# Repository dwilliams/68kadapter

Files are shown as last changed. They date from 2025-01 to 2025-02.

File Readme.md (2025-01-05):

# 68030 to 68020 adapter

Barebones adapter for Motorola processors, converting 68030 to 68020. There is no logic in this, and all the extra features of the 68030 are disabled.

# Why was this made?

To be used with [https://rosco-m68k.com/](https://rosco-m68k.com/) 68020 SBC to test CPUs bought off eBay. Didn't want to buy both the '20 and the '30 version, and now I can test (to a large degree) both versions. The MMU isn't getting tested, but in practice the chips either all work or fail completely to even come up, so it met it's goal.

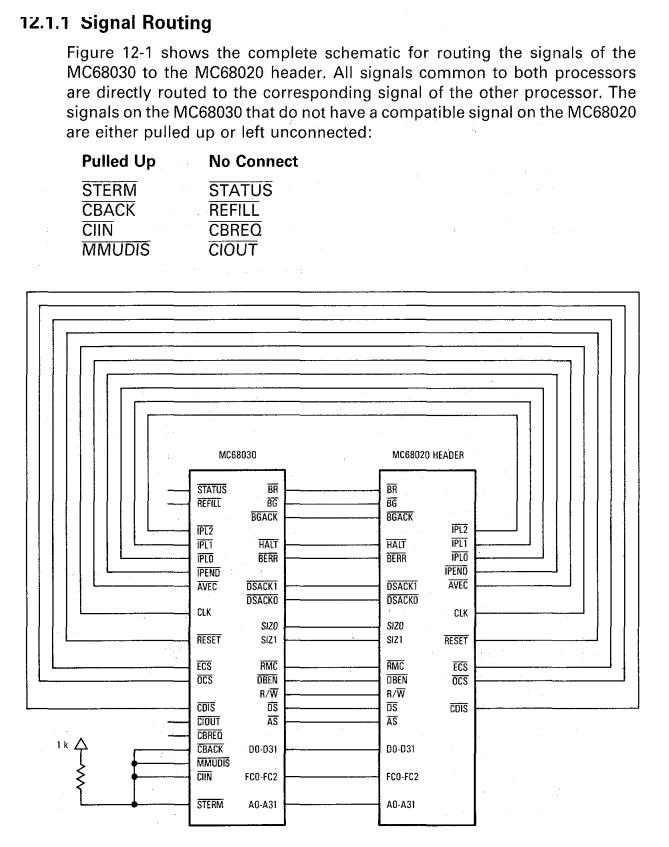
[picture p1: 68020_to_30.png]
Diagram


# Headers and socket

You can buy those off sites like DigiKey or eBay.

For the plug-in 68020 side I used 2.54 mm Single Row Male Pin Headers that I cut up to fill in the rows/columns as needed. They need to be aligned really well otherwise it's close to impossible to plug them into a socket. I used one of the non-populated boards (got 3 made for corrections, test, etc) to hold the pins in place in the right way, but you can also use a 68020 socket and get the same effect. The latter might be too much of a heat sink though, making soldering hard.

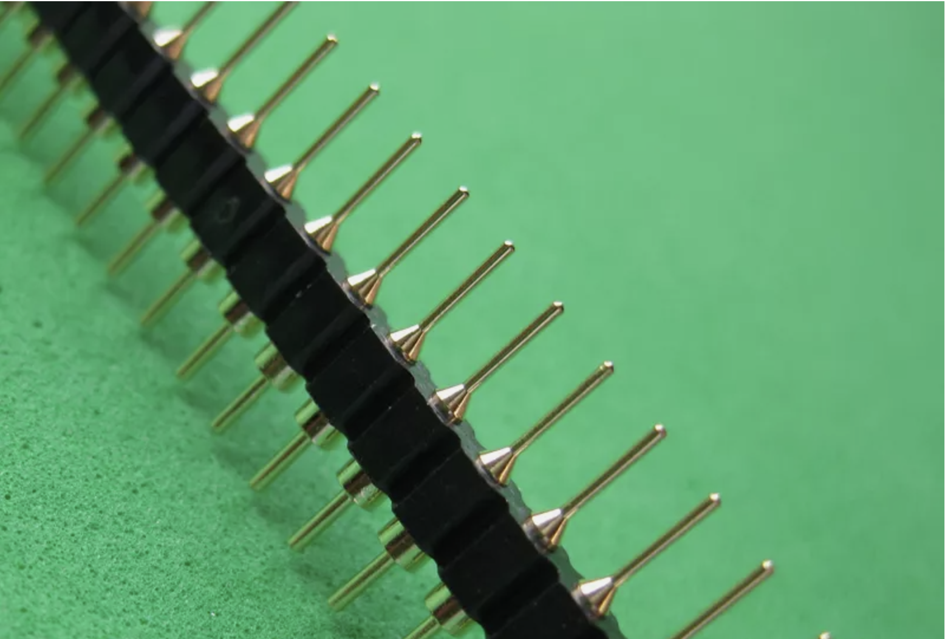
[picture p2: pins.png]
Pin Headers


The 68030 side is just a regular 128 Pin Machine Pin Grid Array PGA IC Socket.

PGA Socket

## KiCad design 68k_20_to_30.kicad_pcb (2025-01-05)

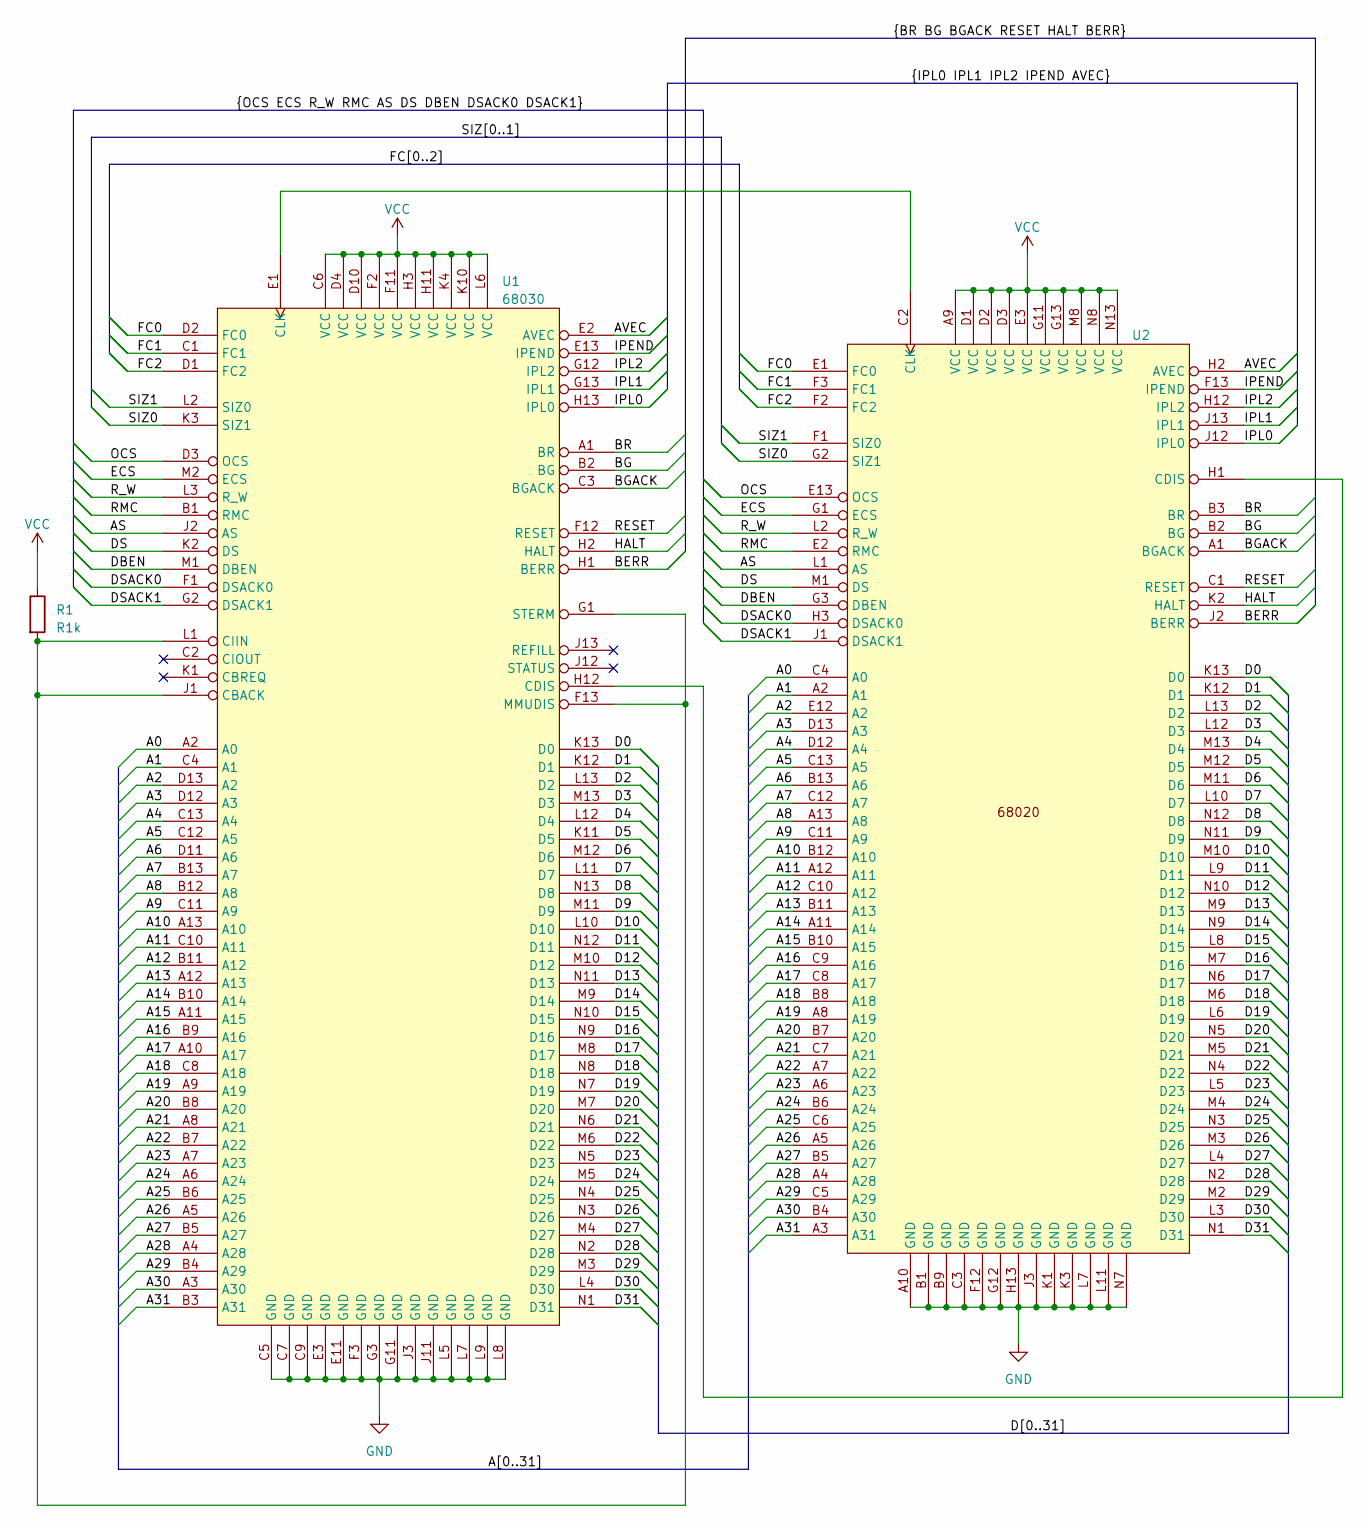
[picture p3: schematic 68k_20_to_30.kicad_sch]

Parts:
R1: R1k; R_Axial_DIN0204_L3.6mm_D1.6mm_P5.08mm_Horizontal
U1: 68030; PGA114_68030
U2: PGA114_68020

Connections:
/A0: U1.A2 (A0), U2.C4 (A0)
/A1: U1.C4 (A1), U2.A2 (A1)
/A2: U1.D13 (A2), U2.E12 (A2)
/A3: U1.D12 (A3), U2.D13 (A3)
/A4: U1.C13 (A4), U2.D12 (A4)
/A5: U1.C12 (A5), U2.C13 (A5)
/A6: U1.D11 (A6), U2.B13 (A6)
/A7: U1.B13 (A7), U2.C12 (A7)
/A8: U1.B12 (A8), U2.A13 (A8)
/A9: U1.C11 (A9), U2.C11 (A9)
/A10: U1.A13 (A10), U2.B12 (A10)
/A11: U1.C10 (A11), U2.A12 (A11)
/A12: U1.B11 (A12), U2.C10 (A12)
/A13: U1.A12 (A13), U2.B11 (A13)
/A14: U1.B10 (A14), U2.A11 (A14)
/A15: U1.A11 (A15), U2.B10 (A15)
/A16: U1.B9 (A16), U2.C9 (A16)
/A17: U1.A10 (A17), U2.C8 (A17)
/A18: U1.C8 (A18), U2.B8 (A18)
/A19: U1.A9 (A19), U2.A8 (A19)
/A20: U1.B8 (A20), U2.B7 (A20)
/A21: U1.A8 (A21), U2.C7 (A21)
/A22: U1.B7 (A22), U2.A7 (A22)
/A23: U1.A7 (A23), U2.A6 (A23)
/A24: U1.A6 (A24), U2.B6 (A24)
/A25: U1.B6 (A25), U2.C6 (A25)
/A26: U1.A5 (A26), U2.A5 (A26)
/A27: U1.B5 (A27), U2.B5 (A27)
/A28: U1.A4 (A28), U2.A4 (A28)
/A29: U1.B4 (A29), U2.C5 (A29)
/A30: U1.A3 (A30), U2.B4 (A30)
/A31: U1.B3 (A31), U2.A3 (A31)
/AS: U1.J2 (AS), U2.L1 (AS)
/AVEC: U1.E2 (AVEC), U2.H2 (AVEC)
/BERR: U1.H1 (BERR), U2.J2 (BERR)
/BG: U1.B2 (BG), U2.B2 (BG)
/BGACK: U1.C3 (BGACK), U2.A1 (BGACK)
/BR: U1.A1 (BR), U2.B3 (BR)
/D0: U1.K13 (D0), U2.K13 (D0)
/D1: U1.K12 (D1), U2.K12 (D1)
/D2: U1.L13 (D2), U2.L13 (D2)
/D3: U1.M13 (D3), U2.L12 (D3)
/D4: U1.L12 (D4), U2.M13 (D4)
/D5: U1.K11 (D5), U2.M12 (D5)
/D6: U1.M12 (D6), U2.M11 (D6)
/D7: U1.L11 (D7), U2.L10 (D7)
/D8: U1.N13 (D8), U2.N12 (D8)
/D9: U1.M11 (D9), U2.N11 (D9)
/D10: U1.L10 (D10), U2.M10 (D10)
/D11: U1.N12 (D11), U2.L9 (D11)
/D12: U1.M10 (D12), U2.N10 (D12)
/D13: U1.N11 (D13), U2.M9 (D13)
/D14: U1.M9 (D14), U2.N9 (D14)
/D15: U1.N10 (D15), U2.L8 (D15)
/D16: U1.N9 (D16), U2.M7 (D16)
/D17: U1.M8 (D17), U2.N6 (D17)
/D18: U1.N8 (D18), U2.M6 (D18)
/D19: U1.N7 (D19), U2.L6 (D19)
/D20: U1.M7 (D20), U2.N5 (D20)
/D21: U1.N6 (D21), U2.M5 (D21)
/D22: U1.M6 (D22), U2.N4 (D22)
/D23: U1.N5 (D23), U2.L5 (D23)
/D24: U1.M5 (D24), U2.M4 (D24)
/D25: U1.N4 (D25), U2.N3 (D25)
/D26: U1.N3 (D26), U2.M3 (D26)
/D27: U1.M4 (D27), U2.L4 (D27)
/D28: U1.N2 (D28), U2.N2 (D28)
/D29: U1.M3 (D29), U2.M2 (D29)
/D30: U1.L4 (D30), U2.L3 (D30)
/D31: U1.N1 (D31), U2.N1 (D31)
/DBEN: U1.M1 (DBEN), U2.G3 (DBEN)
/DS: U1.K2 (DS), U2.M1 (DS)
/DSACK0: U1.F1 (DSACK0), U2.H3 (DSACK0)
/DSACK1: U1.G2 (DSACK1), U2.J1 (DSACK1)
/ECS: U1.M2 (ECS), U2.G1 (ECS)
/FC0: U1.D2 (FC0), U2.E1 (FC0)
/FC1: U1.C1 (FC1), U2.F3 (FC1)
/FC2: U1.D1 (FC2), U2.F2 (FC2)
/HALT: U1.H2 (HALT), U2.K2 (HALT)
/IPEND: U1.E13 (IPEND), U2.F13 (IPEND)
/IPL0: U1.H13 (IPL0), U2.J12 (IPL0)
/IPL1: U1.G13 (IPL1), U2.J13 (IPL1)
/IPL2: U1.G12 (IPL2), U2.H12 (IPL2)
/OCS: U1.D3 (OCS), U2.E13 (OCS)
/RESET: U1.F12 (RESET), U2.C1 (RESET)
/RMC: U1.B1 (RMC), U2.E2 (RMC)
/R_W: U1.L3 (R_W), U2.L2 (R_W)
/SIZ0: U1.K3 (SIZ1), U2.G2 (SIZ1)
/SIZ1: U1.L2 (SIZ0), U2.F1 (SIZ0)
GND: U1.C5 (GND), U1.C7 (GND), U1.C9 (GND), U1.E3 (GND), U1.E11 (GND), U1.F3 (GND), U1.G3 (GND), U1.G11 (GND), U1.J3 (GND), U1.J11 (GND), U1.L5 (GND), U1.L7 (GND), U1.L8 (GND), U1.L9 (GND), U2.A10 (GND), U2.B1 (GND), U2.B9 (GND), U2.C3 (GND), U2.F12 (GND), U2.G12 (GND), U2.H13 (GND), U2.J3 (GND), U2.K1 (GND), U2.K3 (GND), U2.L7 (GND), U2.L11 (GND), U2.N7 (GND)
unnamed: R1.2, U1.F13 (MMUDIS), U1.G1 (STERM), U1.J1 (CBACK), U1.L1 (CIIN)
unnamed: U1.H12 (CDIS), U2.H1 (CDIS)
unnamed: U1.E1 (CLK), U2.C2 (CLK)
VCC: R1.1, U1.C6 (VCC), U1.D4 (VCC), U1.D10 (VCC), U1.F2 (VCC), U1.F11 (VCC), U1.H3 (VCC), U1.H11 (VCC), U1.K4 (VCC), U1.K10 (VCC), U1.L6 (VCC), U2.A9 (VCC), U2.D1 (VCC), U2.D2 (VCC), U2.D3 (VCC), U2.E3 (VCC), U2.G11 (VCC), U2.G13 (VCC), U2.M8 (VCC), U2.N8 (VCC), U2.N13 (VCC)

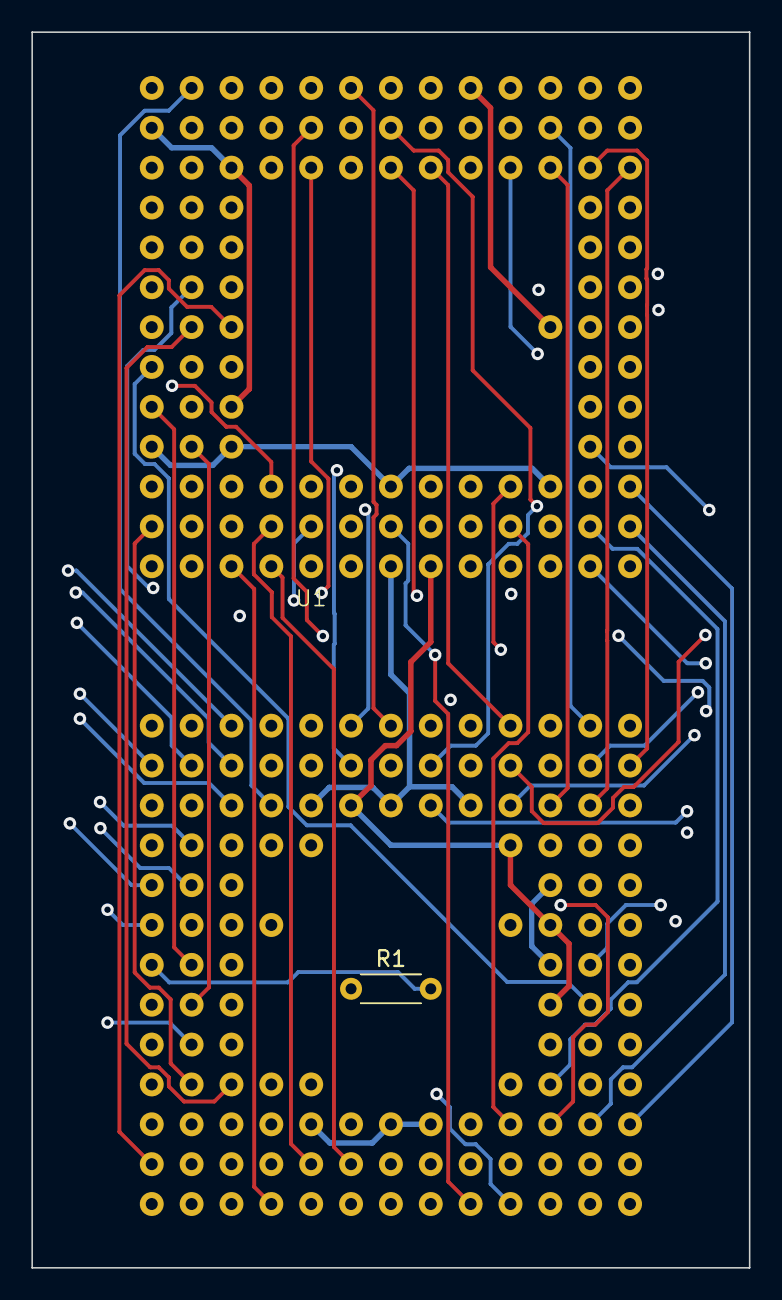
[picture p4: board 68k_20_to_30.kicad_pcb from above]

Board: 4 copper layers, 45.7 x 78.7 mm, 3 parts (0 on the bottom side), 94 nets.
